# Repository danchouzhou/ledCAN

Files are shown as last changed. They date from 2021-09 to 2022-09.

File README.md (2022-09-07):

# ledCAN
A multipurpose buck converter with CAN interface.
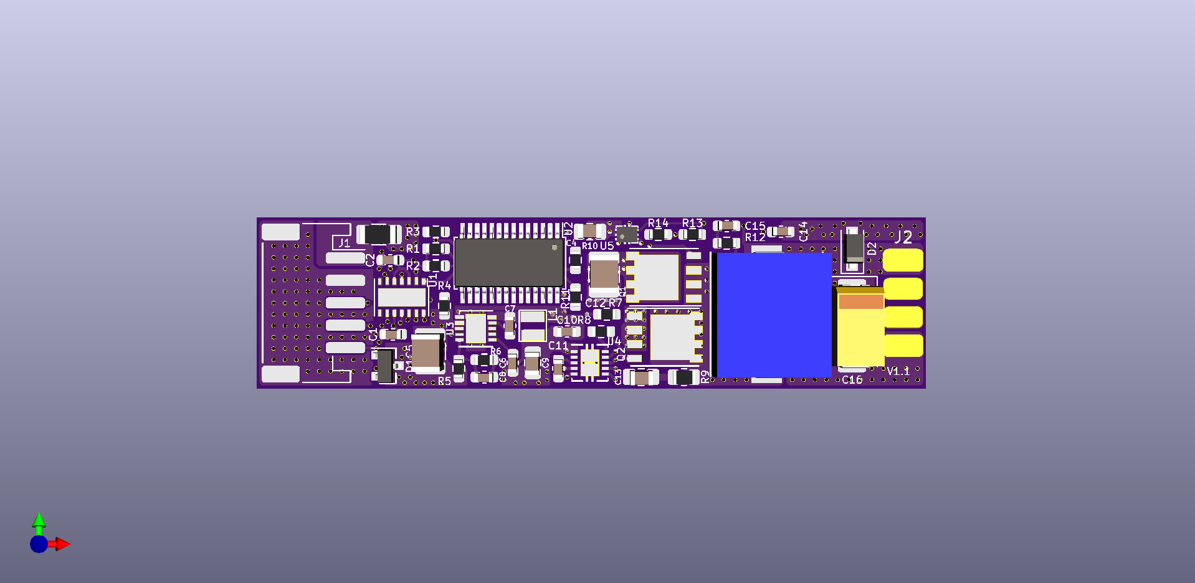
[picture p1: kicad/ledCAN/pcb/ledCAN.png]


## Clone the project
This project work with M0A21BSP submodule from Nuvoton corporation. You need to initialize submodules by passing ``--recurse-submodules`` to the ``git clone`` command.
```
git clone https://github.com/MIH-pi/ledCAN.git --recurse-submodules
```

## Prepare environment
1. Installing tools
```
sudo apt install kicad build-essential gcc-arm-none-eabi libtool libusb-1.0-0-dev
```
2. Build and install customize version of OpenOCD for Nuvoton devices
```
git clone https://github.com/OpenNuvoton/OpenOCD-Nuvoton.git
cd OpenOCD-Nuvoton
./bootstrap
./configure --enable-nulink
make
sudo make install
```

## Credits
We are thankful that [Nuvoton corporation](https://www.nuvoton.com) (MCU),[PANJIT](https://www.panjit.com.tw) (MOSFET), [EDOM Technology](https://www.edomtech.com) (MPS MPQ4569GQ) and [Texas Instruments](https://ti.com) (CAN SBC) provide samples and technical support.

## Datasheet
[Nuvoton NuMicro M0A21/M0A23](https://www.nuvoton.com/export/resource-files/TRM_M0A21_M0A23_Series_EN_Rev1.02.pdf)

## Reference documents

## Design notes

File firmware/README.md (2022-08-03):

# Firmware of the ledCAN module
``M0A21BSP`` BSP submodule from Nuvoton corporation. <br>
``NuLibrary`` My firmware libraries for Nuvoton NuMicro Cortex-M series microcontroller. <br>
``HelloWorld`` Project template for M0A21 serise. <br>
``ISP_CAN`` This is a loader firmware implement ISP function via CAN interface. <br>
``SyncBuck`` This is a buck converter test code with PID controller. <br>
``NeoPixel`` This is a NeoPixel strandtest with a modified version of ``Adafruit_NeoPixel`` library. <br>
``CAN_TxRx`` This is a CAN test code for mode and color select. <br>
``FlashConfig`` This is a code for config bits setup and accessing data flash. <br>
``ledCAN`` The full function firmware for final product. <br>
``id`` Generate CAN ID bianry file from shell script. <br>

## Usage
1. Build a project. 
```
# The output binary file will be in the Objects folder
cd to project directory
make clean && make
```
2. Run OpenOCD-Nuvoton and connect via telenet
```
sudo openocd -f /usr/local/share/openocd/scripts/interface/nulink.cfg -f /usr/local/share/openocd/scripts/target/numicroM0.cfg
telnet localhost 4444
```
2. Erase the whole chip
```
numicro chip_erase
```
3. To program the LDROM
```
flash write_image erase ISP_CAN.bin 0x00100000
```
4. To program the APROM
```
flash write_image erase ledCAN.bin 0x00000000
```
5. To program the config bits
```
# Config 0: 0xFDFFF97E, I/O pull-up, extern POR time, disable reset pin, boot from LDROM, enable data flash
numicro write_isp 0x00300000 0xFDFFF97E
# Config 1: 0x00007E00, DFBA=0x07E00 (data flash base address)
numicro write_isp 0x00300004 0x00007E00
```
6. To program the data flash
```
# numicro write_isp DFBA CAN_ID
numicro write_isp 0x00007E00 0x201
```

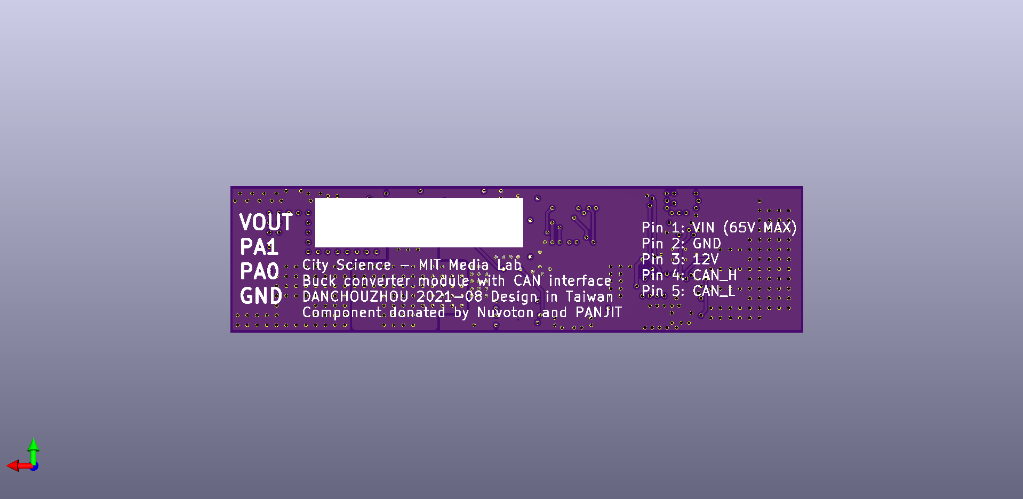
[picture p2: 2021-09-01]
kicad/ledCAN/pcb/ledCAN_back.png

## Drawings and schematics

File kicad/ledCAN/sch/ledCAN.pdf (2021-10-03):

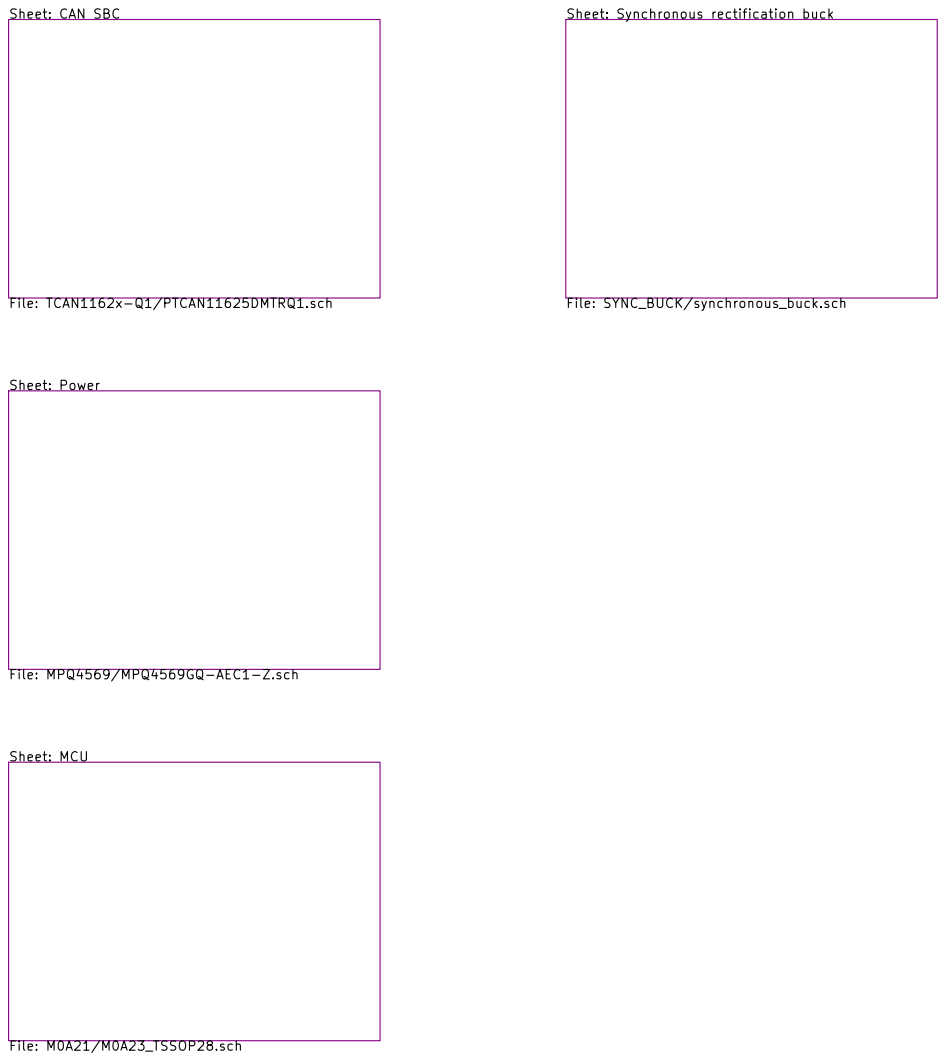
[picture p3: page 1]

Sheet: Synchronous rectification buck

File: TCAN1162x-Q1/PTCAN11625DMTRQ1.sch Sheet: MCU

Sheet: Power File: MPQ4569/MPQ4569GQ-AEC1-Z.sch

danchouzhou@gmail.com
City Science - MIT Media Lab
File: ledCAN.sch Sheet: / DANCHOUZHOU

Id: 1/5 Title: Multi purpose power converter module with CAN bus interface

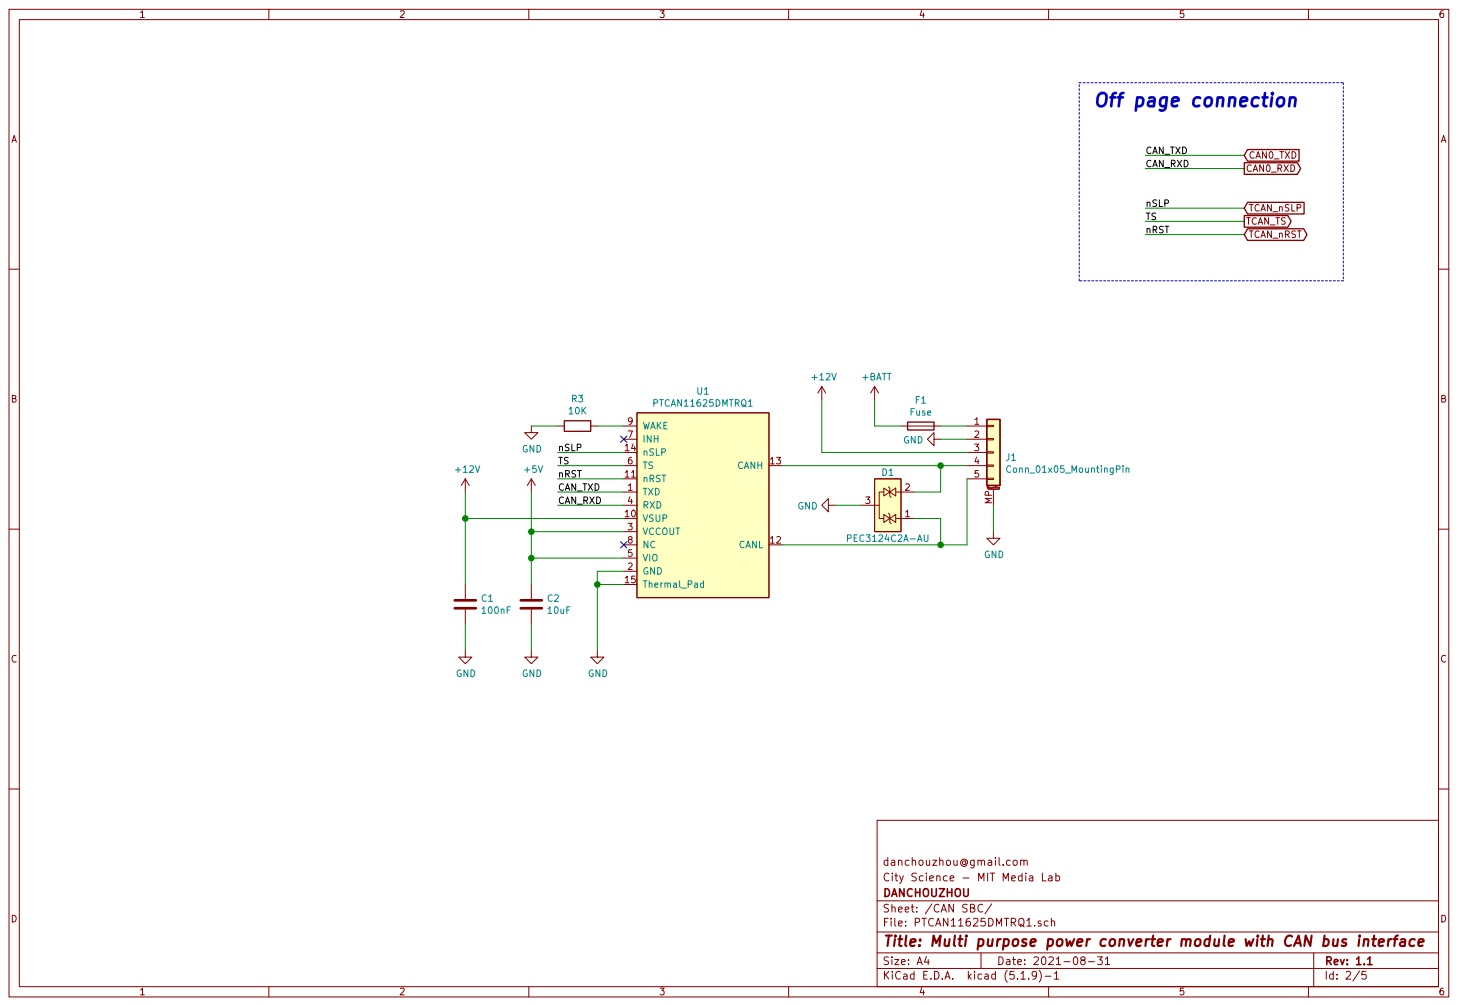
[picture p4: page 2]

danchouzhou@gmail.com
City Science - MIT Media Lab
File: PTCAN11625DMTRQ1.sch Sheet: /CAN SBC/ DANCHOUZHOU

Id: 2/5 Title: Multi purpose power converter module with CAN bus interface

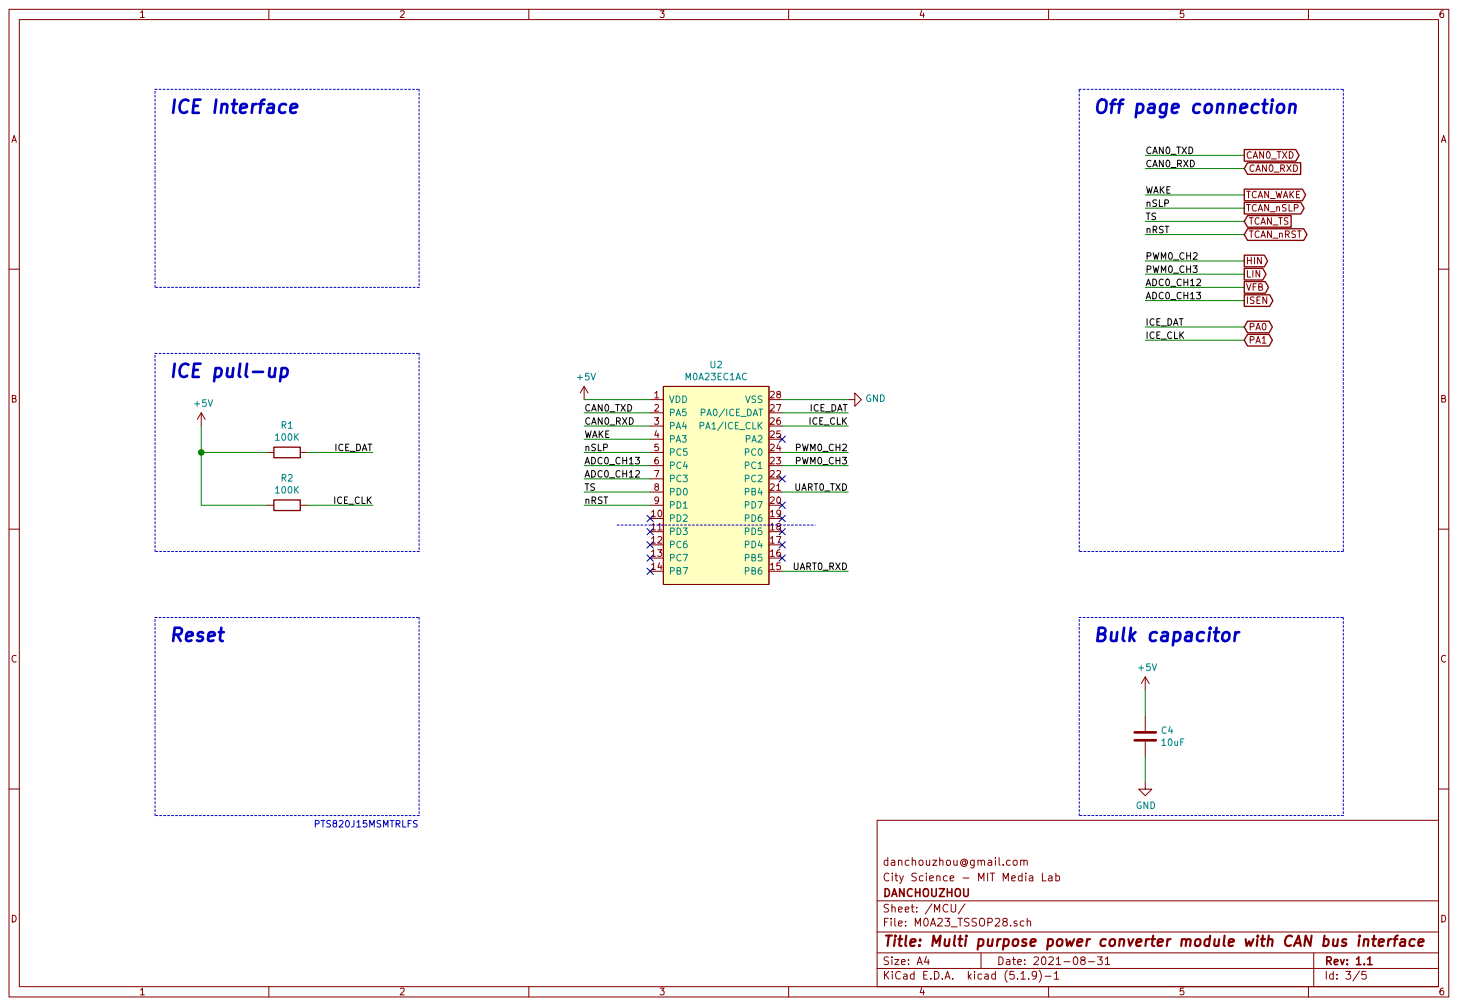
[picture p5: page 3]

danchouzhou@gmail.com
City Science - MIT Media Lab
File: M0A23_TSSOP28.sch Sheet: /MCU/ DANCHOUZHOU

Id: 3/5 Title: Multi purpose power converter module with CAN bus interface

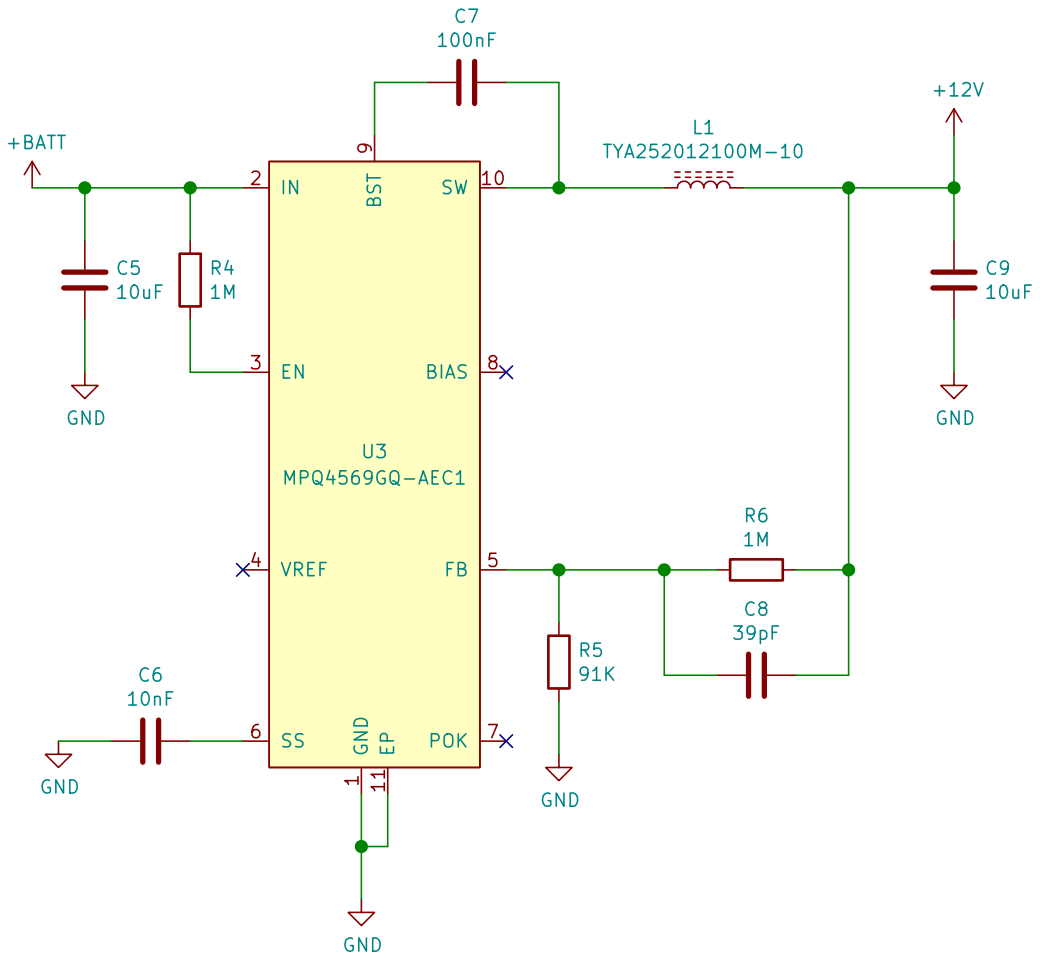
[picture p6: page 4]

danchouzhou@gmail.com
City Science - MIT Media Lab
File: MPQ4569GQ-AEC1-Z.sch Sheet: /Power/ DANCHOUZHOU

Id: 4/5 Title: Multi purpose power converter module with CAN bus interface

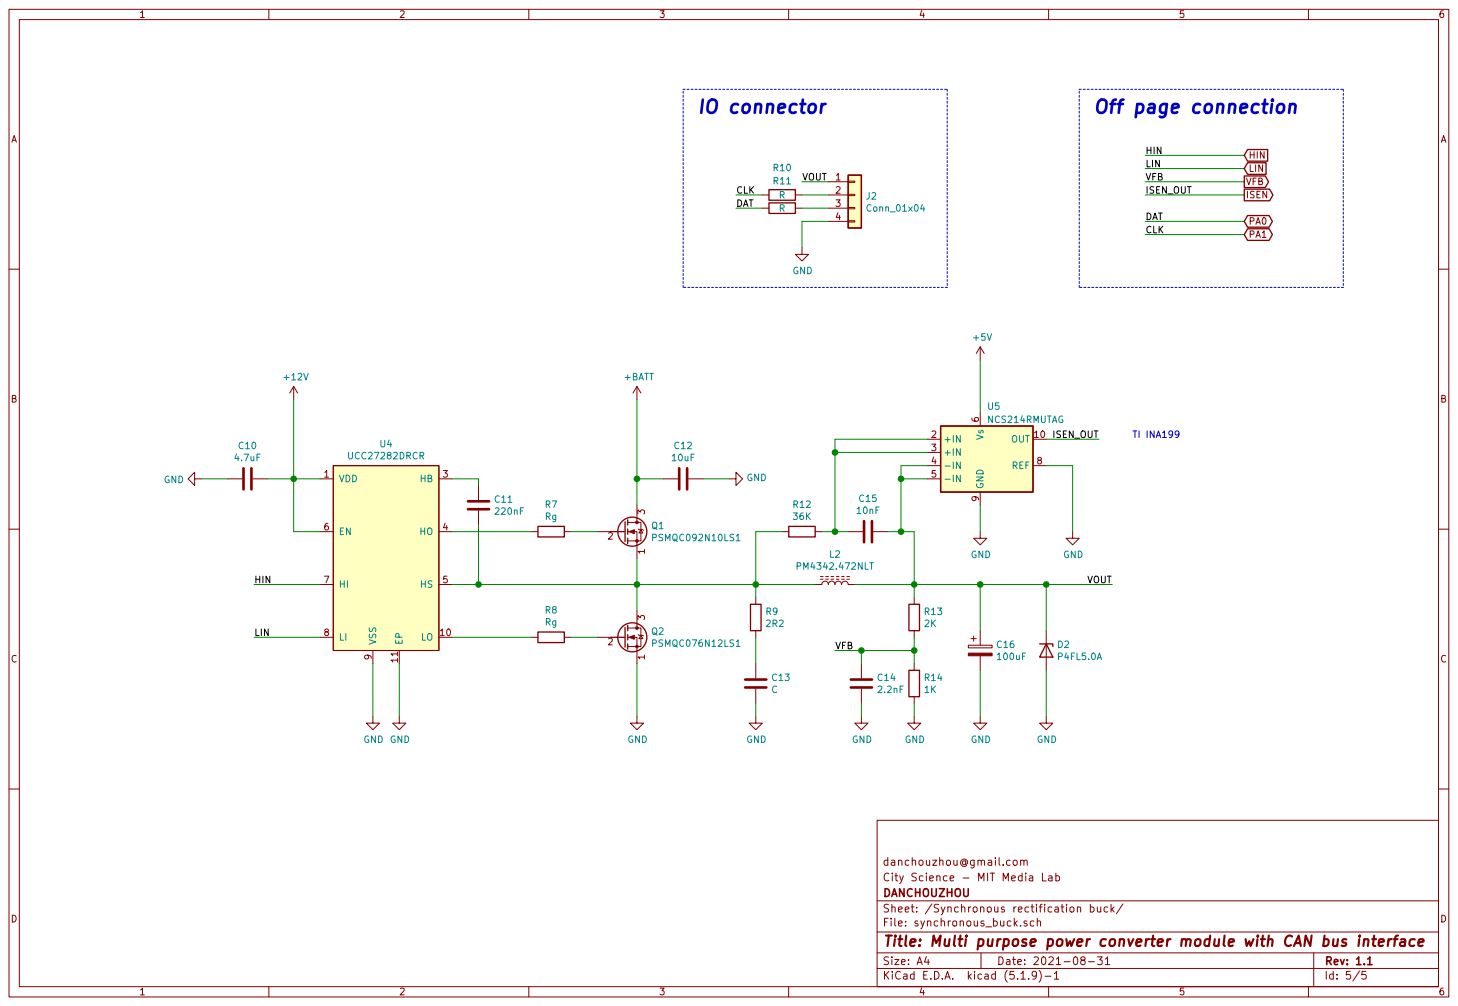
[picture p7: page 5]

danchouzhou@gmail.com
City Science - MIT Media Lab
Sheet: /Synchronous rectification buck/ DANCHOUZHOU

File: synchronous_buck.sch
Id: 5/5 Title: Multi purpose power converter module with CAN bus interface

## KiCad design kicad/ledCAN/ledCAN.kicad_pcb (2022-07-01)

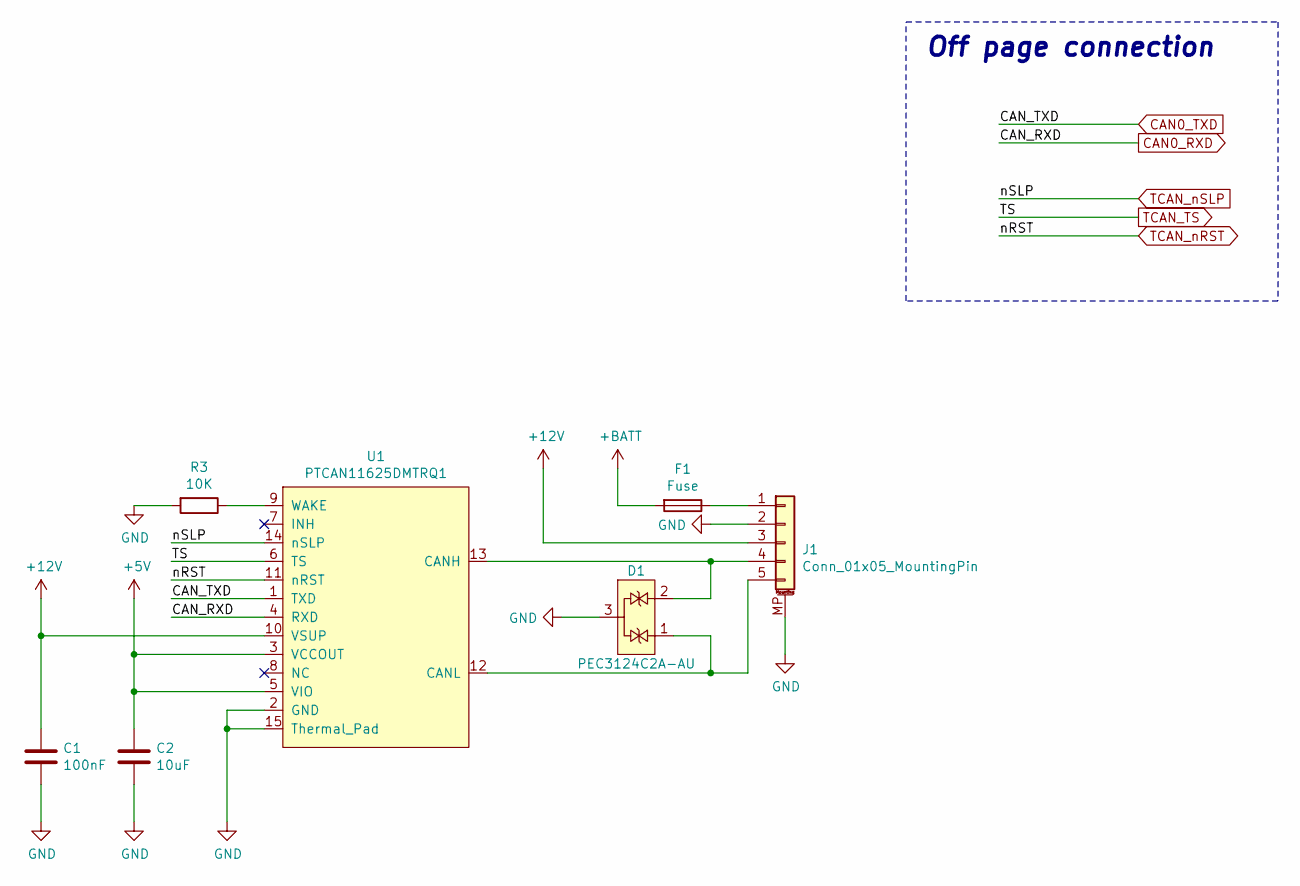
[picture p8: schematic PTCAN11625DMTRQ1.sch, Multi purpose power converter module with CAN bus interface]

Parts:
C1: 100nF; C_0603_1608Metric
C2: 10uF; C_0603_1608Metric
D1: PEC3124C2A-AU; SOT-23; Manufacturer P/N PEC3124C2A-AU_R1_000A1
F1: Fuse; Fuse_1206_3216Metric
J1: Conn_01x05_MountingPin; JST_PH_S5B-PH-SM4-TB_1x05-1MP_P2.00mm_Horizontal
R3: 10K; R_0603_1608Metric
U1: PTCAN11625DMTRQ1; TI_VSON-14_4.5x3.0mm_DMT0014B_ThermalVias

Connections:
+5V: C2.1, U1.3 (VCCOUT), U1.5 (VIO); also elsewhere on the board
+12V: C1.1, J1.3, U1.10 (VSUP); also elsewhere on the board
+BATT: F1.2; also elsewhere on the board
CAN0_RXD: U1.4 (RXD); also elsewhere on the board
CAN0_TXD: U1.1 (TXD); also elsewhere on the board
GND: C1.2, C2.2, D1.3, J1.2, J1.MP (MountPin), R3.2, U1.2 (GND), U1.15 (Thermal_Pad); also elsewhere on the board
unnamed: D1.1, J1.5, U1.12 (CANL)
unnamed: D1.2, J1.4, U1.13 (CANH)
unnamed: F1.1, J1.1
unnamed: R3.1, U1.9 (WAKE)
TCAN_TS: U1.6 (TS); also elsewhere on the board
TCAN_nRST: U1.11 (nRST); also elsewhere on the board
TCAN_nSLP: U1.14 (nSLP); also elsewhere on the board

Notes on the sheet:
Off page connection

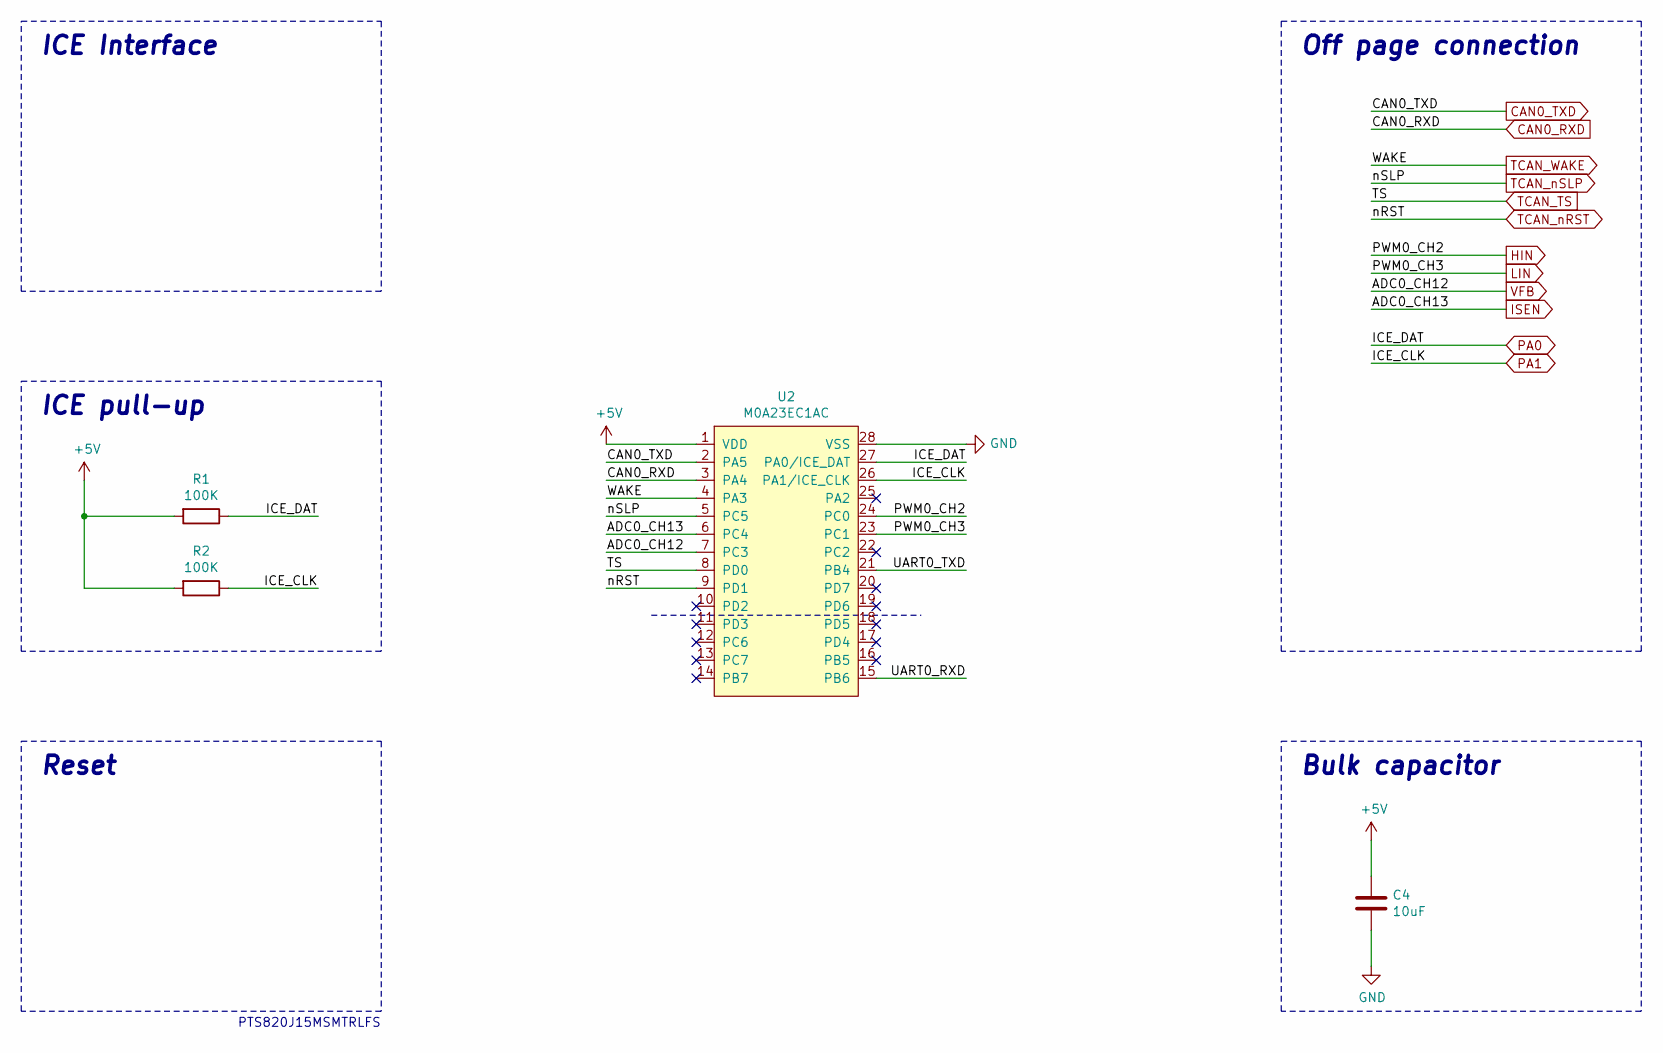
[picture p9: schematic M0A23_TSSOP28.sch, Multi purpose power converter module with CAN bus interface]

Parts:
C4: 10uF; C_0805_2012Metric
R1, R2: 100K; R_0603_1608Metric
U2: M0A23EC1AC; TSSOP-28_4.4x9.7mm_P0.65mm

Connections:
+5V: C4.1, R1.2, R2.2, U2.1 (VDD); also elsewhere on the board
/MCU/UART0_RXD: U2.15 (PB6)
/MCU/UART0_TXD: U2.21 (PB4)
CAN0_RXD: U2.3 (PA4); also elsewhere on the board
CAN0_TXD: U2.2 (PA5); also elsewhere on the board
GND: C4.2, U2.28 (VSS); also elsewhere on the board
HIN: U2.24 (PC0); also elsewhere on the board
ISEN: U2.6 (PC4); also elsewhere on the board
LIN: U2.23 (PC1); also elsewhere on the board
PA0: R1.1, U2.27 (PA0/ICE_DAT); also elsewhere on the board
PA1: R2.1, U2.26 (PA1/ICE_CLK); also elsewhere on the board
TCAN_TS: U2.8 (PD0); also elsewhere on the board
TCAN_WAKE: U2.4 (PA3)
TCAN_nRST: U2.9 (PD1); also elsewhere on the board
TCAN_nSLP: U2.5 (PC5); also elsewhere on the board
VFB: U2.7 (PC3); also elsewhere on the board

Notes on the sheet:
Bulk capacitor
Off page connection
ICE Interface
ICE pull-up
Reset
PTS820J15MSMTRLFS

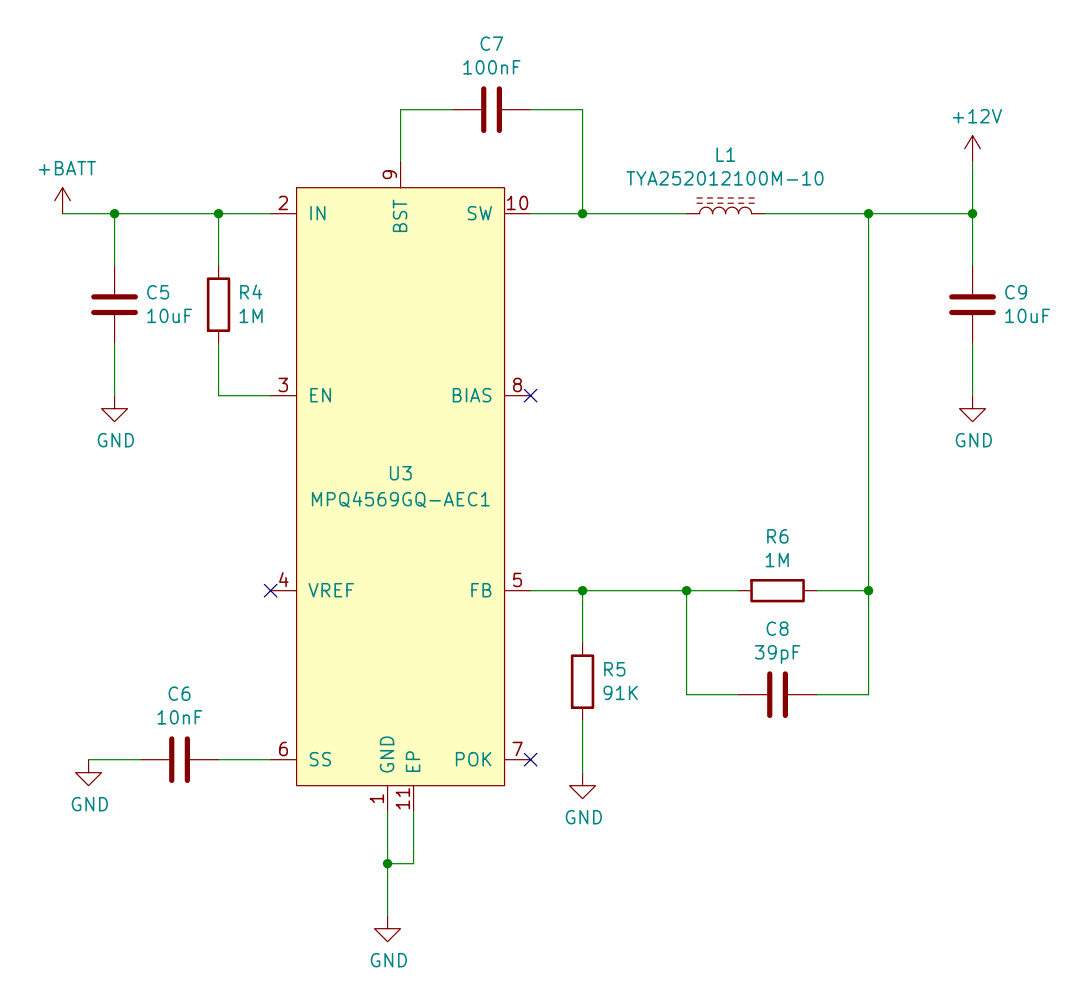
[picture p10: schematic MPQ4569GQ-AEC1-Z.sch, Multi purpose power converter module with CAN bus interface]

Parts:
C5: 10uF; C_1210_3225Metric
C6: 10nF; C_0603_1608Metric
C7: 100nF; C_0603_1608Metric
C8: 39pF; C_0603_1608Metric
C9: 10uF; C_0805_2012Metric
L1: TYA252012100M-10; tya252010-series
R4, R6: 1M; R_0603_1608Metric
R5: 91K; R_0603_1608Metric
U3: MPQ4569GQ-AEC1; QFN-10-1EP_3x3mm_P0.5mm_EP1.7x2.5mm

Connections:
+12V: C8.1, C9.1, L1.2, R6.1; also elsewhere on the board
+BATT: C5.1, R4.1, U3.2 (IN); also elsewhere on the board
GND: C5.2, C6.2, C9.2, R5.2, U3.1 (GND), U3.11 (EP); also elsewhere on the board
unnamed: C6.1, U3.6 (SS)
unnamed: C7.1, L1.1, U3.10 (SW)
unnamed: C7.2, U3.9 (BST)
unnamed: C8.2, R5.1, R6.2, U3.5 (FB)
unnamed: R4.2, U3.3 (EN)

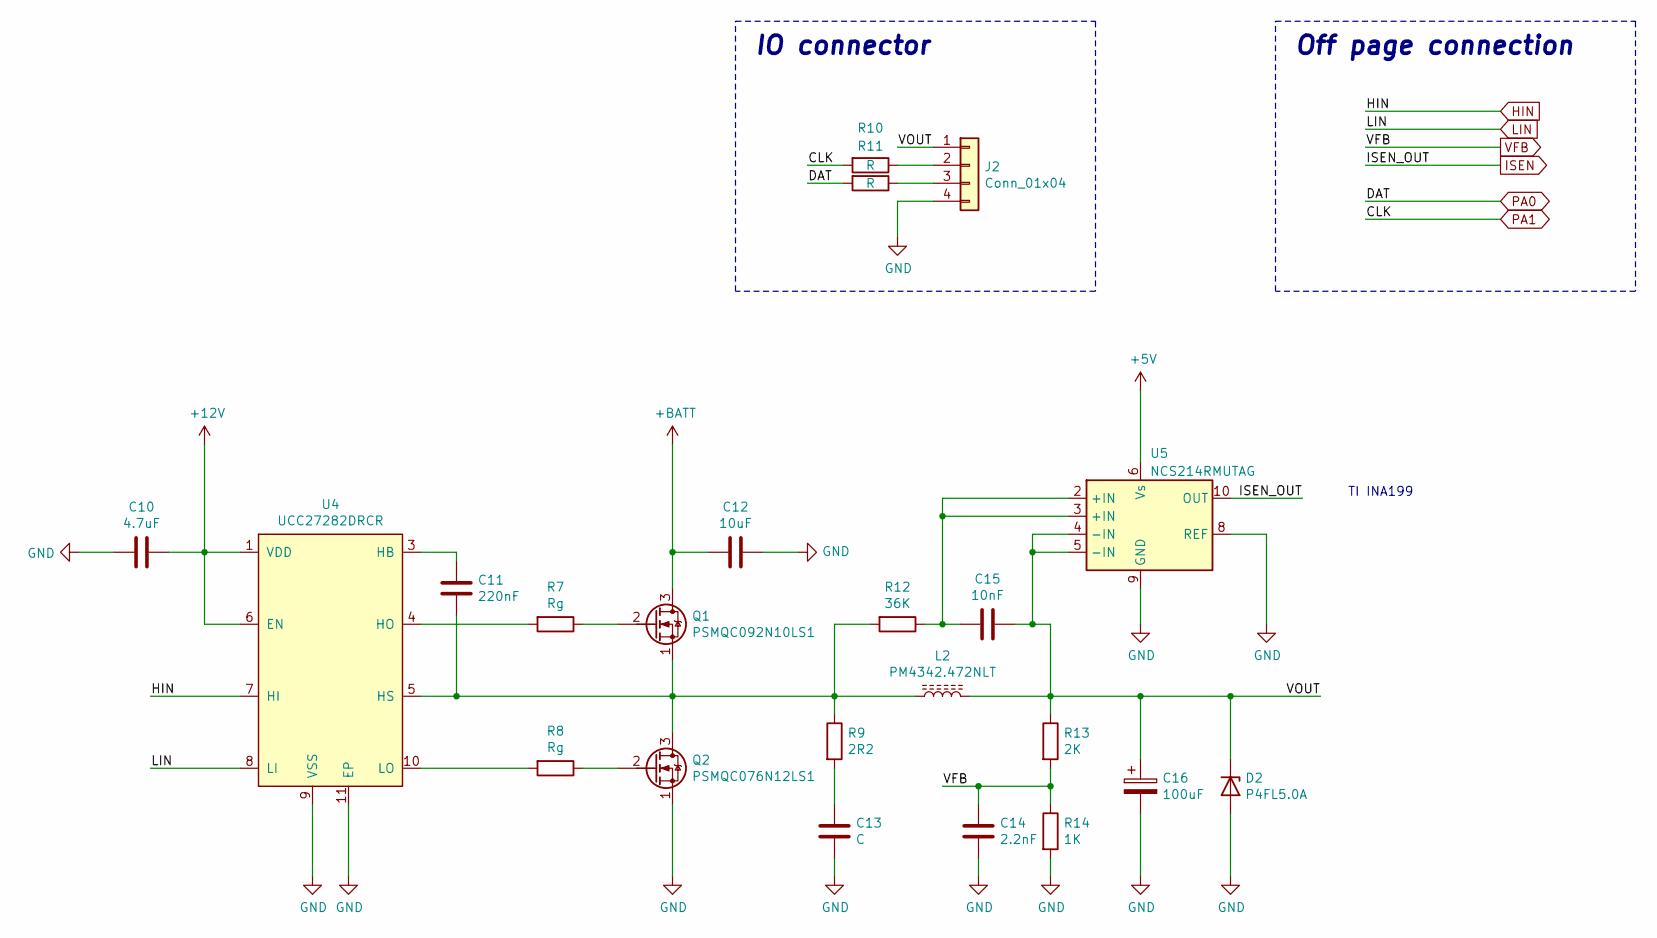
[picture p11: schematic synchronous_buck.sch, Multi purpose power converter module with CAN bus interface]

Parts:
C10: 4.7uF; C_0603_1608Metric
C11: 220nF; C_0603_1608Metric
C12: 10uF; C_1210_3225Metric
C13: C; C_0805_2012Metric_Pad1.18x1.45mm_HandSolder
C14: 2.2nF; C_0603_1608Metric
C15: 10nF; C_0603_1608Metric
C16: 100uF; CP_EIA-7343-31_Kemet-D
D2: P4FL5.0A; D_SOD-123F
J2: Conn_01x04; IO_CONN
L2: PM4342.472NLT; INDPM110100X400N
Q1: PSMQC092N10LS1; PANJIT_DFN5060-8L
Q2: PSMQC076N12LS1; PANJIT_DFN5060-8L
R7, R8: Rg; R_0603_1608Metric
R9: 2R2; R_0805_2012Metric
R10, R11: R; R_0603_1608Metric
R12: 36K; R_0603_1608Metric
R13: 2K; R_0603_1608Metric
R14: 1K; R_0603_1608Metric
U4: UCC27282DRCR; Texas_DRC0010J_ThermalVias
U5: NCS214RMUTAG; UQFN-10_1.4x1.8mm_P0.4mm

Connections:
+5V: U5.6 (Vs); also elsewhere on the board
+12V: C10.1, U4.1 (VDD), U4.6 (EN); also elsewhere on the board
+BATT: C12.2, Q1.3 (D); also elsewhere on the board
/Synchronous rectification buck/VOUT: C15.1, C16.1, D2.1 (A1), J2.1, L2.2, R13.1, U5.4 (-IN), U5.5 (-IN)
GND: C10.2, C12.1, C13.2, C14.2, C16.2, D2.2 (A2), J2.4, Q2.1 (S), R14.2, U4.9 (VSS), U4.11 (EP), U5.8 (REF), U5.9 (GND); also elsewhere on the board
HIN: U4.7 (HI); also elsewhere on the board
ISEN: U5.10 (OUT); also elsewhere on the board
LIN: U4.8 (LI); also elsewhere on the board
unnamed: C11.1, U4.3 (HB)
unnamed: C11.2, L2.1, Q1.1 (S), Q2.3 (D), R9.1, R12.2, U4.5 (HS)
unnamed: C13.1, R9.2
unnamed: C15.2, R12.1, U5.2 (+IN), U5.3 (+IN)
unnamed: J2.2, R10.1
unnamed: J2.3, R11.1
unnamed: Q1.2 (G), R7.1
unnamed: Q2.2 (G), R8.1
unnamed: R7.2, U4.4 (HO)
unnamed: R8.2, U4.10 (LO)
PA0: R11.2; also elsewhere on the board
PA1: R10.2; also elsewhere on the board
VFB: C14.1, R13.2, R14.1; also elsewhere on the board

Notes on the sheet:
Off page connection
TI INA199
IO connector

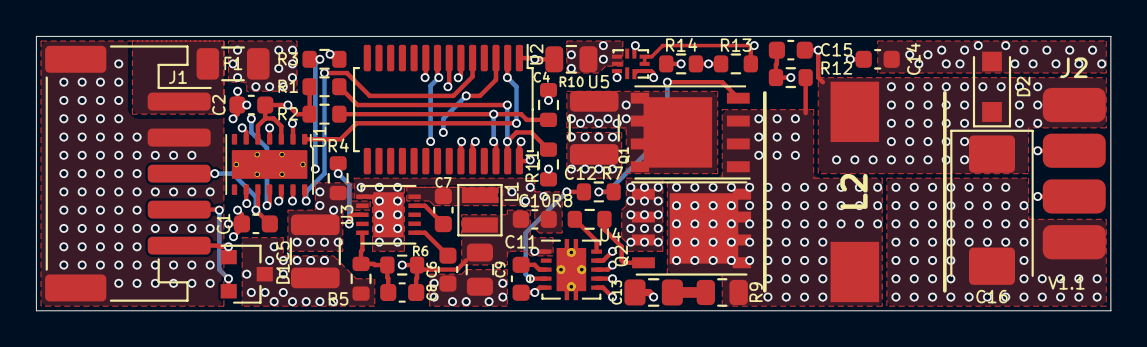
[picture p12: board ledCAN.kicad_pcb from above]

Board: 4 copper layers, 59.7 x 15.2 mm, 43 parts (0 on the bottom side), 35 nets.

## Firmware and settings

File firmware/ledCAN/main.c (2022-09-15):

#include <stdio.h>
#include "NuMicro.h"
#include "NeoPixel.h"
#include "delay.h"
#include "pid.h"
#include "servo.h"
#include "nidec.h"
#include "user_init.h"

/* Hardware configuration */
#define LED_PIN             PA0
#define MAX_BRIGHTNESS      0x80 // 我們店裡的正常是半糖喔

/* Create a NeoPixel object */
STR_NEOPIXEL_T pixels;

void colorWipe(STR_NEOPIXEL_T *pNeoPixel, uint8_t r, uint8_t g, uint8_t b, int wait);

/* Create a Servo object */
STR_SERVO_T servo = {0};

/* Create a Nidec motor object */
STR_NIDEC_T nidec = {0};

/* Create CAN message object */
STR_CANMSG_T rrMsg;
STR_CANMSG_T modeMsg;
STR_CANMSG_T ttMsg;

STR_PID_T PFM_PID = {0};

volatile uint32_t g_u32SyncFlag = 0;
volatile uint32_t g_u32AdCh0Data = 0;
volatile int64_t g_i64EncoderCnt = 0;

/* For encoder counting */
void GPAB_IRQHandler(void)
{
    volatile uint32_t temp;

    /* To check if PA.0 interrupt occurred */
    if(GPIO_GET_INT_FLAG(PA, BIT0))
    {
        GPIO_CLR_INT_FLAG(PA, BIT0);
        //printf("PA.0 INT occurred.\n");
        if (PA1 == 0) // CW
            g_i64EncoderCnt++;
        else // CCW
            g_i64EncoderCnt--;
    }
    else
    {
        /* Un-expected interrupt. Just clear all PA interrupts */
        temp = PA->INTSRC;
        PA->INTSRC = temp;
        //printf("Un-expected interrupts.\n");
    }
}

void ADC_IRQHandler(void)
{
    int32_t i32ConversionData, i32Comp, i32PFM, i32PWM;

    ADC_CLR_INT_FLAG(ADC, ADC_ADF_INT); /* Clear the A/D interrupt flag */

    if(ADC_IS_DATA_VALID(ADC, 12))
        i32ConversionData = ADC_GET_CONVERSION_DATA(ADC, 12);

    if(ADC_IS_DATA_VALID(ADC, 1))
        g_u32AdCh0Data = ADC_GET_CONVERSION_DATA(ADC, 1);

    i32Comp = HDIV_Div(PID_GetCompValue(&PFM_PID, i32ConversionData), 10000);

    //printf("Comp: %d\r\n", i32Comp);

    i32PFM = PWM_GET_CNR(PWM0, 2); // Get current period value
    if ((i32PFM + i32Comp) > 2400)
        i32PFM = 2400; // Min freq=20KHz
    else if ((i32PFM + i32Comp) < 100)
        i32PFM = 100; // Max freq=480KHz
    else
        i32PFM += i32Comp;

    //printf("PFM: %d\r\n", i32PFM);

    PWM_SET_CNR(PWM0, 2, i32PFM);
}

void CAN_ShowMsg(STR_CANMSG_T* Msg)
{
    uint8_t i;
    printf("Read ID=%8X, Type=%s, DLC=%d,Data=",Msg->Id,Msg->IdType?"EXT":"STD",Msg->DLC);
    for(i=0; i<Msg->DLC; i++)
        printf("%02X,",Msg->Data[i]);
    printf("\n\n");
}

void CAN_MsgInterrupt(CAN_T *tCAN, uint32_t u32IIDR)
{
    if(u32IIDR==1)
    {
        //printf("Msg-0 INT and Callback\n");
        CAN_Receive(tCAN, 0,&rrMsg);
        //CAN_ShowMsg(&rrMsg);
        g_u32SyncFlag = 1;
    }
    if(u32IIDR==2)
    {
        //printf("Msg-1 INT and Callback\n");
        CAN_Receive(tCAN, 1,&modeMsg);
        //CAN_ShowMsg(&modeMsg);
    }
}

void CAN0_IRQHandler(void)
{
    uint32_t u8IIDRstatus;

    u8IIDRstatus = CAN->IIDR;

    if(u8IIDRstatus == 0x00008000)        /* Check Status Interrupt Flag (Error status Int and Status change Int) */
    {
        /**************************/
        /* Status Change interrupt*/
        /**************************/
        if(CAN->STATUS & CAN_STATUS_RXOK_Msk)
        {
            CAN->STATUS &= ~CAN_STATUS_RXOK_Msk;   /* Clear Rx Ok status*/

            //printf("RX OK INT\n") ;
        }

        if(CAN->STATUS & CAN_STATUS_TXOK_Msk)
        {
            CAN->STATUS &= ~CAN_STATUS_TXOK_Msk;    /* Clear Tx Ok status*/

            //printf("TX OK INT\n") ;
        }

        /**************************/
        /* Error Status interrupt */
        /**************************/
        if(CAN->STATUS & CAN_STATUS_EWARN_Msk)
        {
            //printf("EWARN INT\n") ;

            /* Do Init to release busoff pin */
            CAN->CON = (CAN_CON_INIT_Msk | CAN_CON_CCE_Msk);
            CAN->CON &= (~(CAN_CON_INIT_Msk | CAN_CON_CCE_Msk));
            while(CAN->CON & CAN_CON_INIT_Msk);
        }

        if(CAN->STATUS & CAN_STATUS_BOFF_Msk)
        {
            //printf("BOFF INT\n") ;
        }
    }
    else if (u8IIDRstatus!=0)
    {
        //printf("=> Interrupt Pointer = %d\n",CAN->IIDR -1);

        CAN_MsgInterrupt(CAN, u8IIDRstatus);

        CAN_CLR_INT_PENDING_BIT(CAN, ((CAN->IIDR) -1));      /* Clear Interrupt Pending */

    }
    else if(CAN->WU_STATUS == 1)
    {
        //printf("Wake up\n");

        CAN->WU_STATUS = 0;                       /* Write '0' to clear */
    }

}

void PID_Init()
{
    PID_SetPoint(&PFM_PID, 1365);

    PID_SetGain(&PFM_PID, -90, 0, 0);
}

void updateLen(STR_NEOPIXEL_T *pNeoPixel, uint16_t u16NewLen)
{
    if(NeoPixel_numPixels(&pixels) != u16NewLen)
    {
        NeoPixel_clear(&pixels);
        NeoPixel_show(&pixels);
        NeoPixel_updateLength(&pixels, u16NewLen);
    }
}

int main()
{
    /* Create a volatile pointer to modeMsg keep the value up to date */
    volatile STR_CANMSG_T *pModeMsg = &modeMsg;

    uint32_t u32ModeID = 0;
    uint32_t u32Mode = 0;

    int64_t i64EncoderCntTmp;

    /* Unlock protected registers */
    SYS_UnlockReg();

    /* Initial system setup */
    SYS_Init();

    /* Init UART0 to 115200-8n1 for print message */
    UART_Open(UART0, 115200);

    /* Connect UART to PC, and open a terminal tool to receive following message */
    printf("Hello World\r\n");

    /* Initial flash configuration */
    FMC_Init();

    /* Read mode ID in data flash */
    u32ModeID = FMC_Read(DATA_FLASH_BASE + MODE_ID_OFFSET);
    printf("Mode ID is: 0x%x\r\n", u32ModeID);

    /* Disable FMC ISP function */
    FMC_Close();

    /* Lock protected registers */
    SYS_LockReg();

    /* Initial CAN module */
    CAN_Init();

    /* Set message object 0 for synchronous arbitration = 0x200 (512) */
    CAN_SetRxMsg(CAN, MSG(0),CAN_STD_ID, 0x200);

    /* Set message object 1 for mode setup arbitration = from data flash */
    CAN_SetRxMsg(CAN, MSG(1),CAN_STD_ID, u32ModeID);

    /* Initialize NeoPixel, will update length later in main functions */
    NeoPixel_begin(&pixels, 0, &LED_PIN, NEO_GRB);

    /* Turn OFF all pixels ASAP */
    //NeoPixel_show(&pixels);

    /* Set the maxmium brightness for NeoPixels */
    NeoPixel_setBrightness(&pixels, MAX_BRIGHTNESS);

    /* Initial PWM0 */
    PWM0_Init();

    /* Initial PID controller */
    PID_Init();

    /* Init TIMER0 for ADC */
    TIMER0_Init();

    /* Initial ADC */
    ADC_Init();

    /* Enable Timer0 counter */
    TIMER_Start(TIMER0);

    /* Enable PWM0 channel 2 counter */
    PWM_Start(PWM0, PWM_CH_2_MASK); // CNTEN2

    /* Got no where to go, just loop forever */
    while(1)
    {
        if (g_u32SyncFlag == 1)
        {
            if (u32Mode != pModeMsg->Data[0])
            {
                if (pModeMsg->Data[0] != 7)
                    servo_detach(&servo);
                
                if (pModeMsg->Data[0] != 8)
                    nidec_detach(&nidec);

                u32Mode = pModeMsg->Data[0];
            }

            switch (pModeMsg->Data[0]) {
                case 0: // idel
                    updateLen(&pixels, modeMsg.Data[1]);
                    NeoPixel_clear(&pixels);
                    NeoPixel_show(&pixels);
                    break;
                case 1: // fill, numberOfLEDs, r, g, b
                    updateLen(&pixels, modeMsg.Data[1]);
                    NeoPixel_fill(&pixels, modeMsg.Data[2], modeMsg.Data[3], modeMsg.Data[4], 0, NeoPixel_numPixels(&pixels));
                    NeoPixel_show(&pixels);
                    break;
                case 2: // wipe, numberOfLEDs, r, g, b, interval (ms)
                    updateLen(&pixels, modeMsg.Data[1]);
                    colorWipe(&pixels, modeMsg.Data[2], modeMsg.Data[3], modeMsg.Data[4], modeMsg.Data[5]);
                    break;
                case 3: // blink, numberOfLEDs, r, g, b, delay (second*10)
                    updateLen(&pixels, modeMsg.Data[1]);
                    NeoPixel_fill(&pixels, modeMsg.Data[2], modeMsg.Data[3], modeMsg.Data[4], 0, NeoPixel_numPixels(&pixels));
                    NeoPixel_show(&pixels);
                    delay(modeMsg.Data[5]*10);
                    NeoPixel_clear(&pixels);
                    NeoPixel_show(&pixels);
                    break;
                case 4: // breath, numberOfLEDs, r, g, b, period (second)
                    updateLen(&pixels, modeMsg.Data[1]);
                    for(int i=0; i<MAX_BRIGHTNESS; i+=((modeMsg.Data[5]>3)?1:5)) // Increase 5 if period <= 3 seconds
                    {
                        NeoPixel_setBrightness(&pixels, i);
                        NeoPixel_fill(&pixels, modeMsg.Data[2], modeMsg.Data[3], modeMsg.Data[4], 0, NeoPixel_numPixels(&pixels));
                        NeoPixel_show(&pixels);
                        //delay((uint32_t)modeMsg.Data[5]*1000/512);
                        delayMicroseconds((uint32_t)modeMsg.Data[5]*((modeMsg.Data[5]>3)?3906:19530)); // 1000000/MAX_BRIGHTNESS/2
                    }
                    for(int i=MAX_BRIGHTNESS; i>=0; i-=((modeMsg.Data[5]>3)?1:5)) // Decrease 5 if period <= 3 seconds
                    {
                        NeoPixel_setBrightness(&pixels, i);
                        NeoPixel_fill(&pixels, modeMsg.Data[2], modeMsg.Data[3], modeMsg.Data[4], 0, NeoPixel_numPixels(&pixels));
                        NeoPixel_show(&pixels);
                        //delay((uint32_t)modeMsg.Data[5]*1000/512);
                        delayMicroseconds((uint32_t)modeMsg.Data[5]*((modeMsg.Data[5]>3)?3906:19530)); // 1000000/MAX_BRIGHTNESS/2
                    }
                    NeoPixel_clear(&pixels);
                    NeoPixel_show(&pixels);
                    NeoPixel_setBrightness(&pixels, MAX_BRIGHTNESS);
                    break;
                case 5: // snake scroll, numberOfLEDs, r, g, b, length of snake, interval (ms)
                    if(modeMsg.Data[1] != NeoPixel_numPixels(&pixels))
                    {
                        NeoPixel_clear(&pixels);
                        NeoPixel_show(&pixels);
                    }
                    updateLen(&pixels, modeMsg.Data[1]);
                    NeoPixel_fill(&pixels, modeMsg.Data[2], modeMsg.Data[3], modeMsg.Data[4], 0, NeoPixel_numPixels(&pixels));
                    for(int i=0; i<NeoPixel_numPixels(&pixels); i++)
                    {
                        if(i<modeMsg.Data[6])
                        {
                            NeoPixel_setPixelColor(&pixels, i, (((uint32_t)modeMsg.Data[2]*2>255)?255:modeMsg.Data[2]*2), (((uint32_t)modeMsg.Data[3]*2>255)?255:modeMsg.Data[3]*2), (((uint32_t)modeMsg.Data[4]*2>255)?255:modeMsg.Data[4]*2));
                        }
                        else
                        {
                            NeoPixel_setPixelColor(&pixels, i, (((uint32_t)modeMsg.Data[2]*2>255)?255:modeMsg.Data[2]*2), (((uint32_t)modeMsg.Data[3]*2>255)?255:modeMsg.Data[3]*2), (((uint32_t)modeMsg.Data[4]*2>255)?255:modeMsg.Data[4]*2));
                            NeoPixel_setPixelColor(&pixels, i-modeMsg.Data[5], modeMsg.Data[2], modeMsg.Data[3], modeMsg.Data[4]);
                        }
                        NeoPixel_show(&pixels);
                        delay(modeMsg.Data[6]);
                    }
                    for(int i=NeoPixel_numPixels(&pixels)-modeMsg.Data[5]; i>=-(int)modeMsg.Data[5]; i--)
                    {
                        if(i<0)
                        {
                            NeoPixel_setPixelColor(&pixels, i+modeMsg.Data[5], modeMsg.Data[2], modeMsg.Data[3], modeMsg.Data[4]);
                        }
                        else
                        {
                            NeoPixel_setPixelColor(&pixels, i, (((uint32_t)modeMsg.Data[2]*2>255)?255:modeMsg.Data[2]*2), (((uint32_t)modeMsg.Data[3]*2>255)?255:modeMsg.Data[3]*2), (((uint32_t)modeMsg.Data[4]*2>255)?255:modeMsg.Data[4]*2));
                            NeoPixel_setPixelColor(&pixels, i+modeMsg.Data[5], modeMsg.Data[2], modeMsg.Data[3], modeMsg.Data[4]);
                        }
                        NeoPixel_show(&pixels);
                        delay(modeMsg.Data[6]);
                    }
                    break;
                case 6: // Get PA1 ADC value every 10ms
                    /* Set PA.1 to input mode */
                    GPIO_SetMode(PA, BIT1, GPIO_MODE_INPUT);

                    /* Configure the PA.1 ADC analog input pins.  */
                    SYS->GPA_MFP0 = (SYS->GPA_MFP0 & ~(SYS_GPA_MFP0_PA1MFP_Msk)) |
                                    (SYS_GPA_MFP0_PA1MFP_ADC0_CH1);

                    /* Disable the PC.3, PC.4 digital input path to avoid the leakage current. */
                    GPIO_DISABLE_DIGITAL_PATH(PA, BIT1);

                    /* Add input channel */
                    ADC->ADCHER = ADC->ADCHER | BIT1;

                    modeMsg.FrameType = CAN_DATA_FRAME;
                    modeMsg.IdType = CAN_STD_ID;
                    modeMsg.Id = u32ModeID;
                    
                    while(pModeMsg->Data[0] == 6) // leave if mode has been change
                    {
                        modeMsg.DLC = 3;
                        //modeMsg.Data[0] = 6;
                        modeMsg.Data[1] = (uint8_t)(g_u32AdCh0Data & 0xFF); // MSB
                        modeMsg.Data[2] = (uint8_t)(g_u32AdCh0Data>>8 & 0x0F); // LSB
                        CAN_Transmit(CAN, MSG(2), &modeMsg); // Use msg 2 transmit
                        delay(10);
                    }

                    /* Set the I/O mode to default */
                    ADC->ADCHER = ADC->ADCHER & (~BIT1);
                    SYS->GPA_MFP0 = (SYS->GPA_MFP0 & ~(SYS_GPA_MFP0_PA1MFP_Msk));
                    GPIO_SetMode(PA, BIT1, GPIO_MODE_OUTPUT);
                    GPIO_ENABLE_DIGITAL_PATH(PA, BIT1);

                    break;
                case 7: // servo, degree
                    servo_attach(&servo);
                    servo_write(&servo, modeMsg.Data[1]);
                    break;
                case 8: // Nidec, duty (0-100), dir (0=CCW, 1=CW)
                    nidec_attach(&nidec);
                    nidec_write(&nidec, modeMsg.Data[1], modeMsg.Data[2] & 0x1);
                    
                    // Stop the Nidec motor if there is no update
                    modeMsg.Data[1] = 0;
                    g_u32SyncFlag = 0;
                    while(modeMsg.Data[1] == 0 || g_u32SyncFlag == 0)
                    {
                        if (timeout(200) == 0)
                        {
                            nidec_write(&nidec, 0, 0);
                            break;
                        }
                    }

                    timeout(0); // Stop the timeout progress

                    break;
                case 9: // Encoder
                    SYS->GPA_MFP0 = (SYS->GPA_MFP0 & ~(SYS_GPA_MFP0_PA0MFP_Msk | SYS_GPA_MFP0_PA1MFP_Msk));
                    GPIO_SetMode(PA, BIT0 | BIT1, GPIO_MODE_QUASI); // PA0, PA1
                    PA0=1; PA1=1; // Pull up the GPIO
                    GPIO_SET_DEBOUNCE_TIME(GPIO_DBCTL_DBCLKSRC_HCLK, GPIO_DBCTL_DBCLKSEL_64);
                    GPIO_ENABLE_DEBOUNCE(PA, BIT0);
                    GPIO_EnableInt(PA, 0, GPIO_INT_RISING);
                    NVIC_EnableIRQ(GPIO_PAPB_IRQn);

                    ttMsg.FrameType = CAN_DATA_FRAME;
                    ttMsg.IdType = CAN_STD_ID;
                    ttMsg.Id = u32ModeID;
                    ttMsg.DLC = 8;

                    while(pModeMsg->Data[0] == 9) // leave if mode has been change
                    {
                        i64EncoderCntTmp = g_i64EncoderCnt;
                        g_i64EncoderCnt = 0;

                        if (pModeMsg->Data[1])
                            i64EncoderCntTmp = 0 - i64EncoderCntTmp;
                        ttMsg.Data[0] = (uint8_t)(i64EncoderCntTmp & 0xFF); // MSB
                        ttMsg.Data[1] = (uint8_t)(i64EncoderCntTmp>>8 & 0xFF);
                        ttMsg.Data[2] = (uint8_t)(i64EncoderCntTmp>>16 & 0xFF);
                        ttMsg.Data[3] = (uint8_t)(i64EncoderCntTmp>>24 & 0xFF);
                        ttMsg.Data[4] = (uint8_t)(i64EncoderCntTmp>>32 & 0xFF);
                        ttMsg.Data[5] = (uint8_t)(i64EncoderCntTmp>>40 & 0xFF);
                        ttMsg.Data[6] = (uint8_t)(i64EncoderCntTmp>>48 & 0xFF);
                        ttMsg.Data[7] = (uint8_t)(i64EncoderCntTmp>>56 & 0xFF); // LSB
                        CAN_Transmit(CAN, MSG(2), &ttMsg); // Use msg 2 transmit
                        delay(100);
                    }

                    GPIO_DisableInt(PA, 0);
                    NVIC_DisableIRQ(GPIO_PAPB_IRQn);
                    PA0=0; PA1=0;

                    break;                
                default: 
                    break;
            }
            
            /* Clear synchronous flag */
            g_u32SyncFlag = 0;
        }
    }
}

// Fill strip pixels one after another with a color. Strip is NOT cleared
// first; anything there will be covered pixel by pixel. Pass in color
// (as a single 'packed' 32-bit value, which you can get by calling
// strip.Color(red, green, blue) as shown in the loop() function above),
// and a delay time (in milliseconds) between pixels.
void colorWipe(STR_NEOPIXEL_T *pNeoPixel, uint8_t r, uint8_t g, uint8_t b, int wait) {
    for(int i=0; i<NeoPixel_numPixels(pNeoPixel); i++) {  // For each pixel in strip...
        NeoPixel_setPixelColor(pNeoPixel, i, r, g, b);  //  Set pixel's color (in RAM)
        NeoPixel_show(pNeoPixel);                       //  Update strip to match
        delay(wait);                                       //  Pause for a moment
    }
}

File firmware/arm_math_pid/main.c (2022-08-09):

#include <stdio.h>
#include "NuMicro.h"
#include "delay.h"
#include "analog.h"
#include "arm_math.h"

arm_pid_instance_q15 PID;
int16_t g_i16Target, g_i16Current, g_i16Error, g_i16Duty; // PID control

void TMR0_IRQHandler(void)
{
    if(TIMER_GetIntFlag(TIMER0) == 1)
    {
        g_i16Current = analogRead(12);
        g_i16Error = g_i16Target - g_i16Current;
        g_i16Duty = arm_pid_q15(&PID, g_i16Error) / 10;

        if(g_i16Duty < 0)
            g_i16Duty = 0;
        if(g_i16Duty > 100)
            g_i16Duty = 100;

        /* Set PWM0 timer duty */
        PWM_SET_CMR(PWM0, 2, g_i16Duty);

        /* Toggle GPIO indicate the interrupt */
        GPIO_TOGGLE(PD4);

        /* Clear Timer0 time-out interrupt flag */
        TIMER_ClearIntFlag(TIMER0);
    }
}

/**
  * @brief      Read Built-in Band-Gap conversion value
  * @param[in]  None
  * @return     Built-in Band-Gap conversion value
  * @details    This function is used to read Band-Gap conversion value.
  */
__STATIC_INLINE uint32_t FMC_ReadBandGap(void)
{
    FMC->ISPCMD = FMC_ISPCMD_READ_UID;            /* Set ISP Command Code */
    FMC->ISPADDR = 0x70u;                         /* Must keep 0x70 when read Band-Gap */
    FMC->ISPTRG = FMC_ISPTRG_ISPGO_Msk;           /* Trigger to start ISP procedure */
#if ISBEN
    __ISB();
#endif                                            /* To make sure ISP/CPU be Synchronized */
    while(FMC->ISPTRG & FMC_ISPTRG_ISPGO_Msk) {}  /* Waiting for ISP Done */

    return FMC->ISPDAT & 0xFFF;
}

void SYS_Init(void)
{
    /* Enable HIRC clock (Internal RC 48MHz) */
    CLK_EnableXtalRC(CLK_PWRCTL_HIRCEN_Msk);

    /* Wait for HIRC clock ready */
    CLK_WaitClockReady(CLK_STATUS_HIRCSTB_Msk);

    /* Select HCLK clock source as HIRC and HCLK source divider as 1 */
    CLK_SetHCLK(CLK_CLKSEL0_HCLKSEL_HIRC, CLK_CLKDIV0_HCLK(1));

    /* Enable UART0 clock */
    CLK_EnableModuleClock(UART0_MODULE);

    /* Enable PWM0 module clock */
    CLK_EnableModuleClock(PWM0_MODULE);

    /* Enable ADC module clock */
    CLK_EnableModuleClock(ADC_MODULE);

    /* Enable TIMER module clock */
    CLK_EnableModuleClock(TMR0_MODULE);

    /* Switch UART0 clock source to HIRC */
    CLK_SetModuleClock(UART0_MODULE, CLK_CLKSEL1_UART0SEL_HIRC, CLK_CLKDIV0_UART0(1));

    /* Switch ADC clock source to HIRC, set divider to 96, ADC clock is 500 KHz */
    CLK_SetModuleClock(ADC_MODULE, CLK_CLKSEL2_ADCSEL_HIRC, CLK_CLKDIV0_ADC(96));

    /* Update System Core Clock */
    SystemCoreClockUpdate();

    /* Set PB multi-function pins for UART0 RXD=PB.6 and TXD=PB.4 */
    SYS->GPB_MFP1 = (SYS->GPB_MFP1 & ~(SYS_GPB_MFP1_PB4MFP_Msk | SYS_GPB_MFP1_PB6MFP_Msk)) |        \
                    (SYS_GPB_MFP1_PB4MFP_UART0_TXD | SYS_GPB_MFP1_PB6MFP_UART0_RXD);

    /* Set PC multi-function pins for PWM0 Channel 2 */
    SYS->GPC_MFP0 = (SYS->GPC_MFP0 & ~(SYS_GPC_MFP0_PC0MFP_Msk)) | SYS_GPC_MFP0_PC0MFP_PWM0_CH2;

    /* Configure the PC.3 ADC analog input pins. */
    SYS->GPC_MFP0 = (SYS->GPC_MFP0 & ~(SYS_GPC_MFP0_PC3MFP_Msk)) | SYS_GPC_MFP0_PC3MFP_ADC0_CH12;
}

void PWM_Init()
{
    /* Set PWM0 timer clock prescaler */
    PWM_SET_PRESCALER(PWM0, 2, 47); // 48MHz/(47+1)=1MHz

    /* Set counter to up counting */
    PWM0->CTL1 = (PWM0->CTL1 & ~(PWM_CTL1_CNTTYPE2_Msk)) | (PWM_UP_COUNTER << PWM_CTL1_CNTTYPE2_Pos);

    /* Set PWM0 duty */
    PWM_SET_CMR(PWM0, 2, 0);

    /* Set PWM0 period */
    PWM_SET_CNR(PWM0, 2, 99); // 1MHz/(99+1)=10KHz

    /* Set output level at zero, compare up, period(center) and compare down of specified channel */
    PWM_SET_OUTPUT_LEVEL(PWM0, PWM_CH_2_MASK, PWM_OUTPUT_HIGH, PWM_OUTPUT_LOW, PWM_OUTPUT_NOTHING, PWM_OUTPUT_NOTHING);

    /* Enable output of PWM0 channel 2 */
    PWM_EnableOutput(PWM0, PWM_CH_2_MASK);

    /* Enable PWM0 channel 2 counter (PWM_CNT2) */
    PWM_Start(PWM0, PWM_CH_2_MASK);
}

void ADC_Init()
{
    /* Disable the PC.3 digital input path to avoid the leakage current. */
    GPIO_DISABLE_DIGITAL_PATH(PC, BIT3);

    /* Enable ADC converter */
    ADC_POWER_ON(ADC);
    
    /* Set input mode as single-end, Single mode */
    ADC_Open(ADC, ADC_ADCR_DIFFEN_SINGLE_END, ADC_ADCR_ADMD_SINGLE_CYCLE, 0);
}

void TMR0_Init()
{
    /* Open Timer0 in periodic mode */
    TIMER_Open(TIMER0, TIMER_PERIODIC_MODE, 1000);

    /* Enable Timer0 interrupt */
    TIMER_EnableInt(TIMER0);

    /* Enable Timer0 NVIC */
    NVIC_EnableIRQ(TMR0_IRQn);
}

void ARM_PID_Init(arm_pid_instance_q15 *pPID)
{
    pPID->Kp = 2500;
    pPID->Ki = 1200;
    pPID->Kd = 0;

    arm_pid_init_q15(pPID, 1);
}

void Note_Configure()
{
    printf("\n\n");
    printf("+------------------------------------------------------------------------+\n");
    printf("|  About the ARM DSP_Lib PID example code configure                      |\n");
    printf("+------------------------------------------------------------------------+\n");
    printf("|   This example perform a simple way to test the DSP_Lib PID library.   |\n");
    printf("|   We will use PWM feed into a low-pass filter and read the output      |\n");
    printf("|   voltage by ADC.                                                      |\n");
    printf("|   1.Make a RC low-pass filter circuit on your bread board              |\n");
    printf("|   2.Feed PWM output into the filter use Vout as ADC input              |\n");
    printf("|   3.Use a scope or multimeter to measure the output voltage            |\n");
    printf("|                                                                        |\n");
    printf("|  |--------|       _____  R=1K                                          |\n");
    printf("|  |        |------[_____]-----------@ Vout                              |\n");
    printf("|  |        |PWM               |                                         |\n");
    printf("|  |  M0A21 |     _____________|                                         |\n");
    printf("|  |        |     |            |                                         |\n");
    printf("|  |        |------          -----                                       |\n");
    printf("|  |--------|ADC             ----- C=10uF                                |\n");
    printf("|       |                      |                                         |\n");
    printf("|       |                      |                                         |\n");
    printf("|       |                      |                                         |\n");
    printf("|     -----                  -----                                       |\n");
    printf("|      ---                    ---                                        |\n");
    printf("|       -                      -                                         |\n");
    printf("+------------------------------------------------------------------------+\n");
}
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

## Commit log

2021-08-16 Add KiCad files
    [M0A23_TSSOP28.sch, MPQ4569GQ-AEC1-Z.sch, PTCAN11625DMTRQ1.sch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]
2021-08-25 Update schematic PDF
2021-08-26 Fix silkscreen mistake, add labeling area
    [ledCAN.kicad_pcb]
2021-09-01 Fix MOSFET footprint mistake
    [M0A23_TSSOP28.sch, MPQ4569GQ-AEC1-Z.sch, PTCAN11625DMTRQ1.sch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]
2021-09-01 Add PCB back side image
2021-09-06 Add buck converter firmware
2021-09-08 Change R6 value
    [MPQ4569GQ-AEC1-Z.sch, ledCAN.kicad_pcb]
2021-09-29 Add ledCAN
2021-10-01 Fix snake scroll issue
    [main.c]
2021-10-02 Change inductor
    [synchronous_buck.sch]
2021-10-03 Change feedback circuit value
    [synchronous_buck.sch]
2021-10-04 Add buck converter
2021-10-05 Update A/D sample rate
2021-10-15 Change transmit message object avoid from receive issues
    [main.c]
2022-01-01 Change pin mode resolving method
2022-05-08 Add servo
2022-06-14 Fix GPIO mode while leaving Mode 6 (ADC)
    [main.c]
2022-06-16 Add PWM setup
2022-06-16 Move MFP config prevent from programmer error
    [main.c]
2022-06-16 Add servo test code
2022-06-16 Create servo library
2022-06-16 Add some servo function temporarily
2022-06-16 Add servo library
2022-06-16 Add servo_attached()
2022-06-20 Update issue date
    [ledCAN.kicad_pcb]
2022-06-21 Add Nidec motor control
2022-06-21 Fix PWM_WGCTL sequence
2022-06-21 Add Nidec motor testing code
2022-06-21 Add Nidec motor controll
2022-06-22 Move servo library into Library path
2022-06-22 Move pid library into Library path
2022-06-22 Update PWM settings for buck converter
2022-06-22 Fix PWM precaler setting
2022-06-29 Fix CAN DLC overlay issue
    [main.c]
2022-06-30 Stop the Nidec motor if lost the connection
2022-07-01 Update fabrication origin
    [ledCAN.kicad_pcb]
2022-07-05 Add encoder
2022-07-06 Fix shift count overflow
    [main.c]
2022-07-06 Pull up GPIO and fix data field issue
    [main.c]
2022-07-06 Add inverting option for encoder
    [main.c]
2022-07-29 Fix the residual in breath mode
    [main.c]
2022-08-01 Fix snake scroll mode data field issue
    [main.c]
2022-08-05 Update PID gain
2022-08-09 Use timer to get accurate sampling time
2022-08-09 Update PID config
2022-09-07 Update path
    [M0A23_TSSOP28.sch, MPQ4569GQ-AEC1-Z.sch, PTCAN11625DMTRQ1.sch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]
2022-09-15 Fix the auto stop feature
    [main.c]
